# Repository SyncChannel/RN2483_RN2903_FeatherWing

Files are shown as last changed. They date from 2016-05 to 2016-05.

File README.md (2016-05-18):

# RN2483_RN2903_FeatherWing

This FeatherWing adds a Microchip RN2483 or RN2903 LoRaWAN module to Adafruit Feather. It also includes a power LED and an LED connected to GPIO10 of the RN module for debugging or status indication. The parts values are shown in the schematic.

This PCB design is tested and functional. BUT! I DO NOT recommend that you use it. The width of the module and the spacing of the Feather headers prevents a proper footprint for the RN module from being used. The pads are very small and very close to the headers. Even with a small iron tip, it is extremely difficult to hand solder. You MUST check carefully for bridges between the castellations of the module and header pins with magnification after soldering it.

Upon request, I have uploaded the Eagle files to this repo. I will not be doing a blog post article on this one.

Dan Watson

syncchannel.blogspot.com

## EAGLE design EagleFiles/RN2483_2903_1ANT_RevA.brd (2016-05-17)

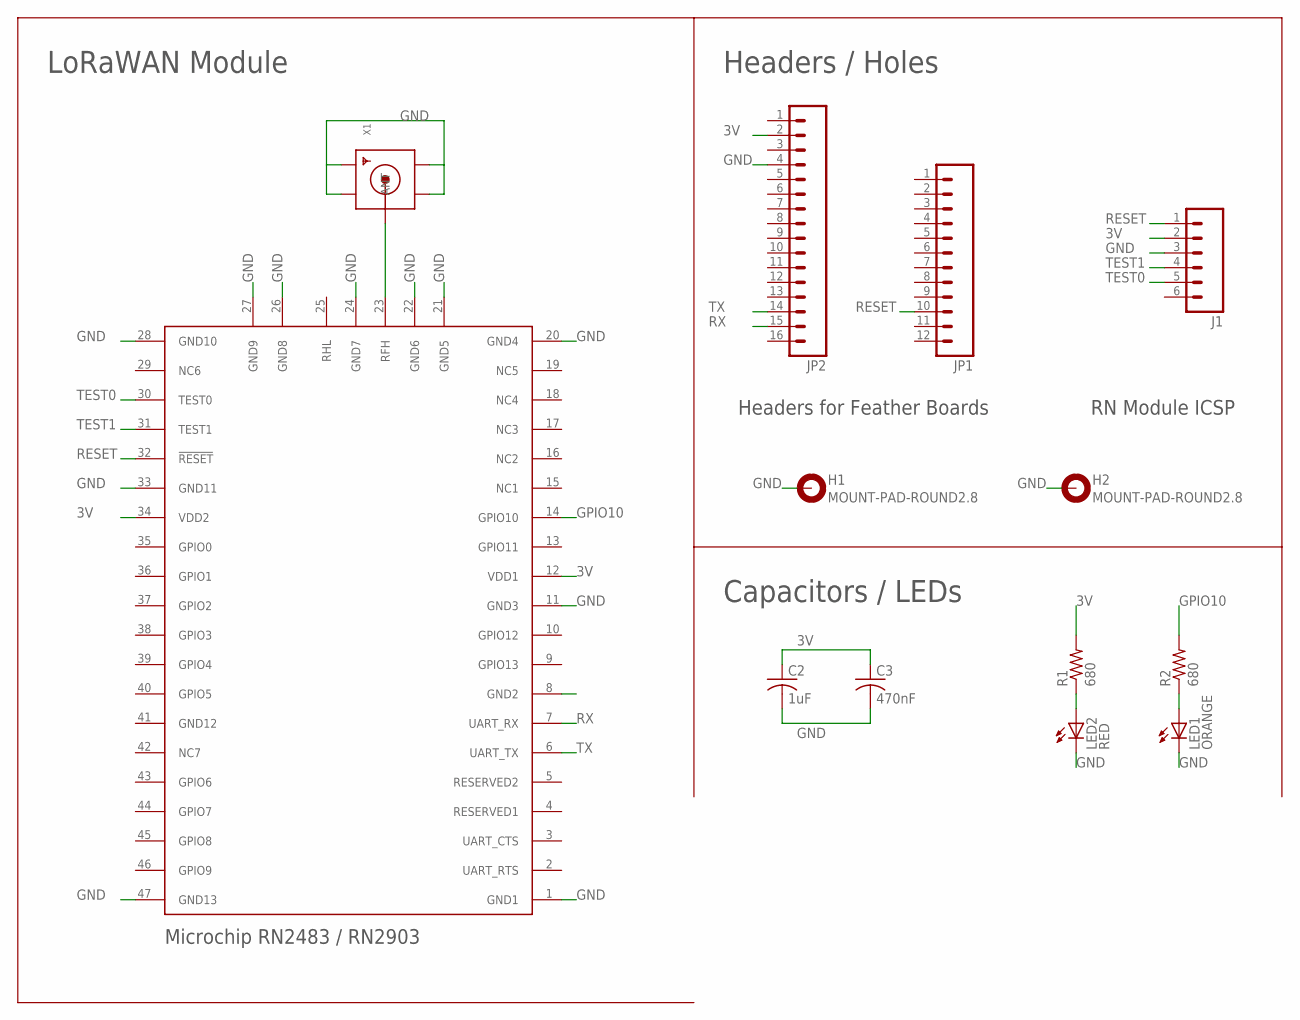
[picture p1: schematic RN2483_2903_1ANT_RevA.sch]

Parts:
C2: 1uF; C0603
C3: 470nF; C0603
H1, H2: MOUNT-PAD-ROUND2.8; 2,8-PAD
J1: M06SILK_FEMALE_PTH; 1X06
JP1: M12NO_SILK; 1X12_NO_SILK
JP2: M161X16_NO_SILK; 1X16_NO_SILK
LED1: ORANGE; CHIPLED_0805
LED2: RED; CHIPLED_0805
R1, R2: 680; R0603
U$2: RN2483/2903
X1: SMACONNECTOR_EDGE; SMA_EDGELAUNCH

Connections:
3V: C2.1, C3.1, J1.2, JP2.2, R1.2, U$2.12 (VDD1), U$2.34 (VDD2)
GND: C2.2, C3.2, H1.B2,8, H2.B2,8, J1.3, JP2.4, LED1.C, LED2.C, U$2.1 (GND1), U$2.11 (GND3), U$2.20 (GND4), U$2.21 (GND5), U$2.22 (GND6), U$2.24 (GND7), U$2.26 (GND8), U$2.27 (GND9), U$2.28 (GND10), U$2.33 (GND11), U$2.47 (GND13), X1.GND@1 (GND4), X1.GND@2 (GND3), X1.GND@3 (GND2), X1.GND@4 (GND1)
GPIO10: R2.2, U$2.14 (GPIO10)
unnamed: LED1.A, R2.1
unnamed: U$2.23 (RFH), X1.P (ANT)
unnamed: LED2.A, R1.1
RESET: J1.1, JP1.10, U$2.32 (!RESET)
RX: JP2.15, U$2.7 (UART_RX)
TEST0: J1.5, U$2.30 (TEST0)
TEST1: J1.4, U$2.31 (TEST1)
TX: JP2.14, U$2.6 (UART_TX)

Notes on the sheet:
Headers for Feather Boards
Headers / Holes
Capacitors / LEDs
RN Module ICSP
LoRaWAN Module
Microchip RN2483 / RN2903

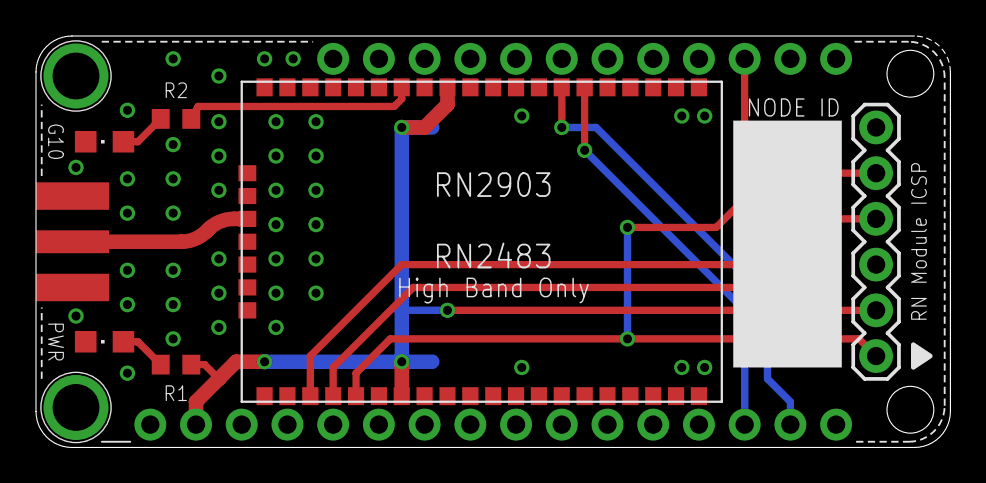
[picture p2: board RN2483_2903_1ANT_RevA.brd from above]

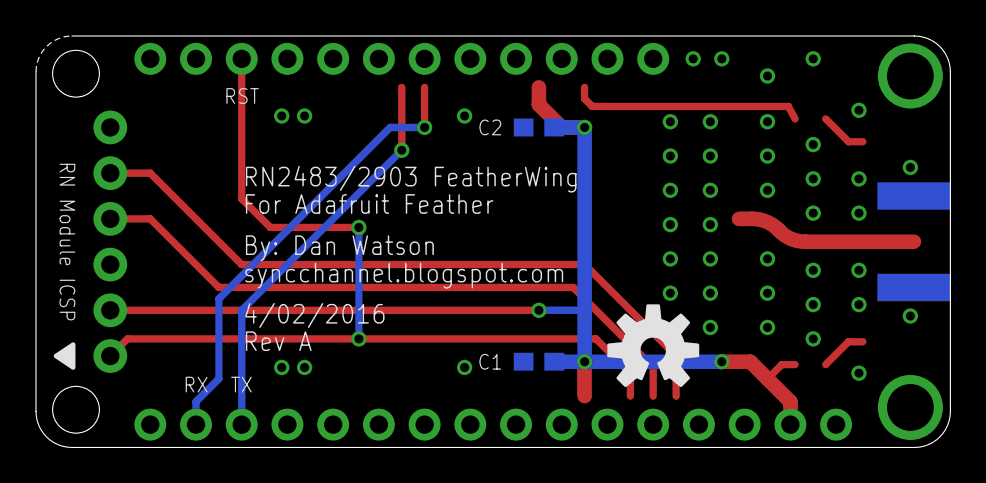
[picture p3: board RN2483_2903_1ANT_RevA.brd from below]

Board: 2 copper layers, 50.8 x 22.9 mm, 14 parts (3 on the bottom side), 11 nets.

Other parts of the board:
U$1: OSHW-LOGO-M

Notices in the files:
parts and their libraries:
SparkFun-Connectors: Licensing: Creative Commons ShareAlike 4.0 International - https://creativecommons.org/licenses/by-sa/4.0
